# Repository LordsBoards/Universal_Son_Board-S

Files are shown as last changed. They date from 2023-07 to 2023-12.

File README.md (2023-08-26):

# Uninversal sonboard series #1 slim

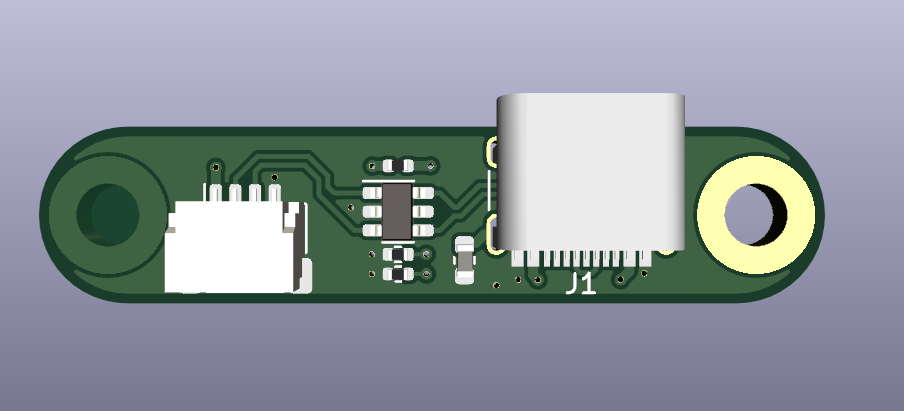
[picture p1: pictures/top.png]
top


I changed a bunch of stuff on the series s UDB because some design changes were needed
- Back to the old JST. Pico EZMate is rated for too few mating cycles
- Different USB routing. I wouldn't recommend running anything higher than USB fullspeed (12mbps) over a long jst w/o shielding. pls don't run high speed usb over a daughterboard
- Different parts. The USBLC6 I used lets you get away without an external ESD diode on your power/ground lines
- Added some mousebites. should be easier to panelize 
- Some smaller footprints
- Changed to the way cooler squiggly U.S. resistor symbol 🦅🇺🇸🦅🇺🇸🦅🇺🇸🦅🇺🇸

Everything should be just as available on JLC so hav fun =^)

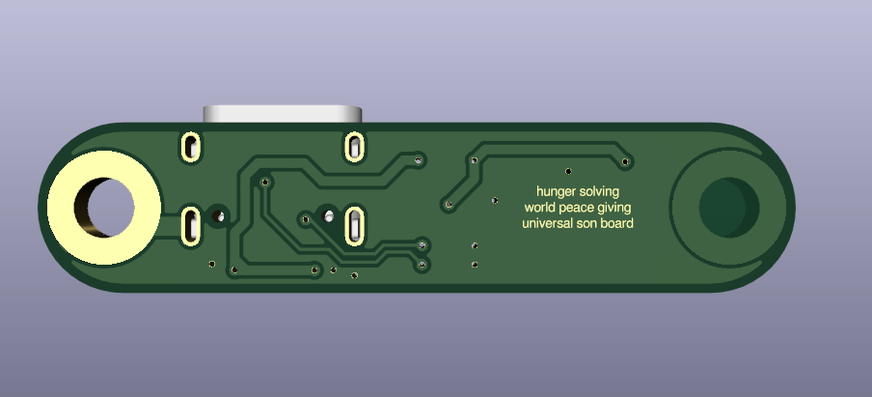
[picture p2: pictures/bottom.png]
bottom


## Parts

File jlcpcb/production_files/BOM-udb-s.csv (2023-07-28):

Comment | Designator | Footprint | LCSC
5.1k | R1,R2 | R_0402_1005Metric | C105872
SM04B-SRSS | J2 | JST_SH_SM04B-SRSS-TB_1x04-1MP_P1.00mm_Horizontal | C160404
TYPE-C-31-M-12 | J1 | USB_C_Receptacle_HRO_TYPE-C-31-M-12 | C165948
USBLC6-2SC6 | U2 | SOT-23-6 | C2827654
1A PTC | F2 | Fuse_0402_1005Metric | C914087
100R @ 100MHz | FB1 | L_0603_1608Metric | C96995

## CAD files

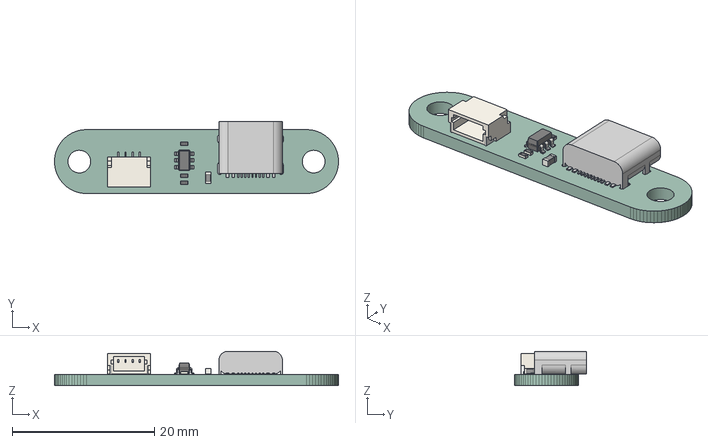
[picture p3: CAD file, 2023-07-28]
3d file/universal_son_board.STEP
40.0 x 10.2 x 4.85 mm
_autosave-udb-s PCB

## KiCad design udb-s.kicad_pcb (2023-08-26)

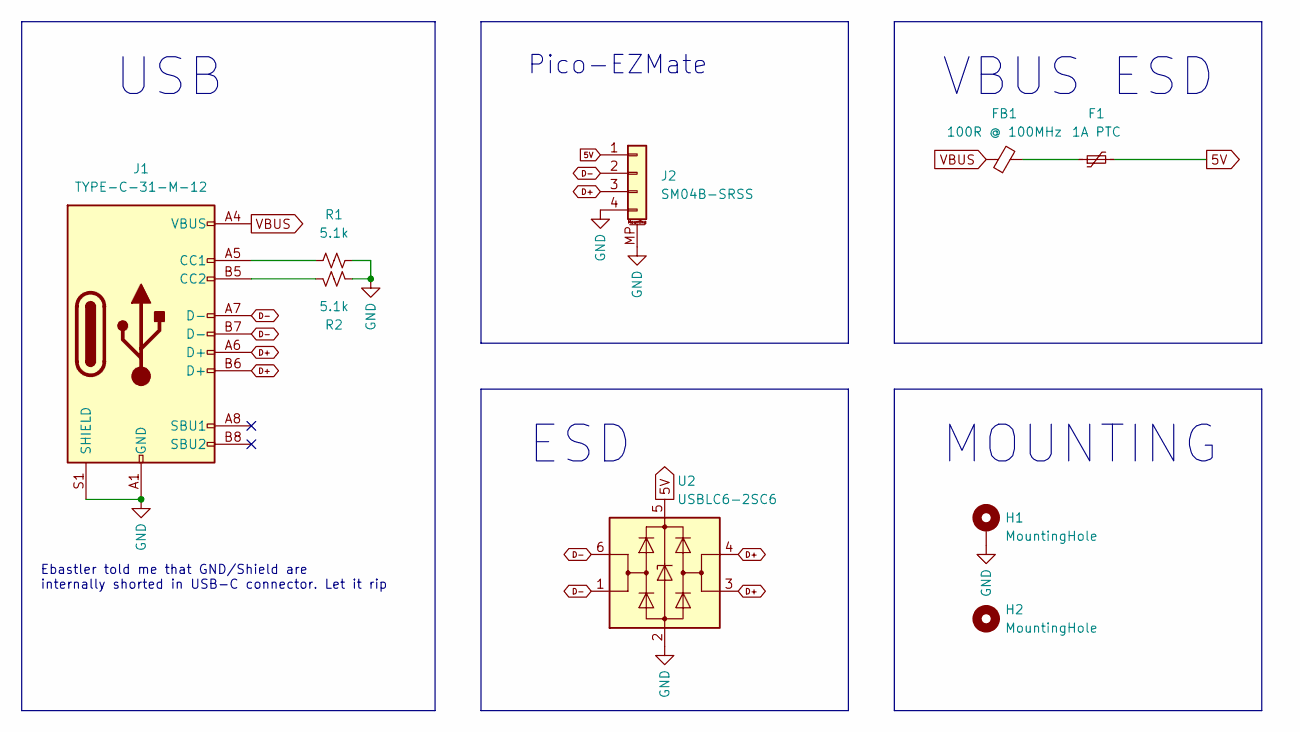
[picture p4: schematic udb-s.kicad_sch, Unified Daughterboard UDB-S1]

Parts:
F1: 1A PTC; Fuse_0402_1005Metric; LCSC Part Number C914087
FB1: 100R @ 100MHz; L_0603_1608Metric; LCSC Part Number C96995
H1: MountingHole; MountingHole_3.2mm_M3_DIN965_Pad_TopBottom
H2: MountingHole; MountingHole_3.2mm_M3_DIN965_Pad_TopOnly
J1: TYPE-C-31-M-12; USB_C_Receptacle_HRO_TYPE-C-31-M-12; Manufacturer Part Number TYPE-C-31-M-12; LCSC Part Number C165948
J2: SM04B-SRSS; JST_SH_SM04B-SRSS-TB_1x04-1MP_P1.00mm_Horizontal; Manufacturer Part Number SM04B-SRSS-TB; LCSC Part Number C160404
R1, R2: 5.1k; R_0402_1005Metric; LCSC Part Number C105872
U2: USBLC6-2SC6; SOT-23-6; Manufacturer Part Number Many; LCSC Part Number C2827654

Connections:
5V: F1.2, J2.1, U2.5 (VBUS)
D+: J1.A6 (D+), J1.B6 (D+), J2.3, U2.3 (I/O2), U2.4 (I/O2)
D-: J1.A7 (D-), J1.B7 (D-), J2.2, U2.1 (I/O1), U2.6 (I/O1)
GND: H1.1, J1.A1 (GND), J1.A12 (GND), J1.B1 (GND), J1.B12 (GND), J1.S1 (SHIELD), J2.4, J2.MP (MountPin), R1.2, R2.2, U2.2 (GND)
unnamed: F1.1, FB1.2
unnamed: J1.A5 (CC1), R1.1
unnamed: J1.B5 (CC2), R2.1
VBUS: FB1.1, J1.A4 (VBUS), J1.A9 (VBUS), J1.B4 (VBUS), J1.B9 (VBUS)

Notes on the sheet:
ESD
VBUS ESD
Ebastler told me that GND/Shield are internally shorted in USB-C connector. Let it rip
USB
MOUNTING
Pico-EZMate

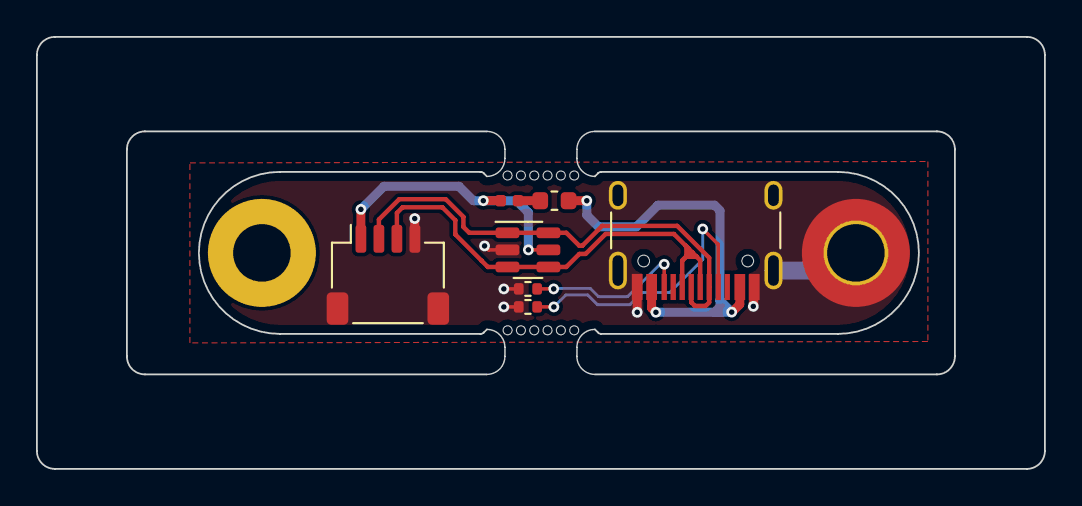
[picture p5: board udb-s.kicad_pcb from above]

Board: 4 copper layers, 56.0 x 24.0 mm, 9 parts (0 on the bottom side), 8 nets.

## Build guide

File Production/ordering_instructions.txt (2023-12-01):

Ordering Instructions:
Panel dimensions: 134.70 x 194.94 mm.
Solder Mask: Red (Default)
Silkscreen: White (Default)
Layers: 4
Finish: HASL Lead-free (Default)
Thickness: 1.6mm (Default)
Copper weight: 1oz (Default)
Minimum track width: 0.16mm (6.30mil)
Minimum via drill: 0.30mm (11.81mil)

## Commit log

2023-08-06 changed the layout so it can be assembled by jlc :)
    [udb-s-CuBottom.gbr, udb-s-CuIn1.gbr, udb-s-CuIn2.gbr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]
2023-08-26 Adjusted ferrite bead location and changed mousebites
    [udb-s.kicad_pcb, udb-s.kicad_sch]
2023-12-01 Modified board edges for easier panelization by JLC. Changed 5.1k resistor value.
